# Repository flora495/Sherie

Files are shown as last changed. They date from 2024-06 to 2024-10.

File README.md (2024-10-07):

# Sherie
Sherieはオーソリニアな40％キーボードです。

## 組み立て方法
ほとんどの部品は実装済みです。
リセットスイッチとキーソケットだけはんだ付けしてください。
そのあと組み立ててください。

## ファームウェア書き込み
QMK toolboxを使って.hexファイルをキーボードに書き込んでください。QMK MSYSやpromicro web updaterでは書き込めない可能性があります。

## VIA/REMAP
viaのキーマップを書き込んだ上で
jsonファイルは以下を読み込ませることで、via/remapを使用することができます。
qmk_firmware\sherie\keymaps\via\sherie.json 

## コマンド
cd 
`cd /c/Users/F/qmk_firmware/keyboards/sherie`
コンパイル
`qmk compile -kb sherie -km default`
`qmk compile -kb sherie -km via`
フラッシュ(フラッシュはQMK toolboxを使うことを推奨します)
`qmk flash -kb sherie -km default`

## memo

USBとかの周りはGNDベタにしたほうがいいかも。
udb-sのPCBを参照。

## Ref
[1]https://note.com/copkbd/n/n587afde1812e

ATMEGA32U4直付の手順は以下を参照します。
[2]https://wiki.ai03.com/books/pcb-design/chapter/pcb-designer-guide

[3]https://taro-hayashi.github.io/LetsMakeaKeypadWithAtmega32u2/

typeC周りの回路
[4]https://github.com/Unified-Daughterboard/UDB-S

静電気対策（特に金属ケースの場合は参照）
[5]https://gist.github.com/s-show/286ffb1f5d9c886b514ff7a37e6d8d37

ベタGNDとか
[6]https://taro-hayashi.github.io/LetsMakeaKeypadWithAtmega32u2/

[7]https://qiita.com/Sugimoto_Yuuki/items/860ca6a57c2501f1cbab

[8]https://docs.qmk.fm/driver_installation_zadig

## バグ
QMK MSYSでflashできない場合
以下のようなエラーが出てflashに失敗する場合があります。

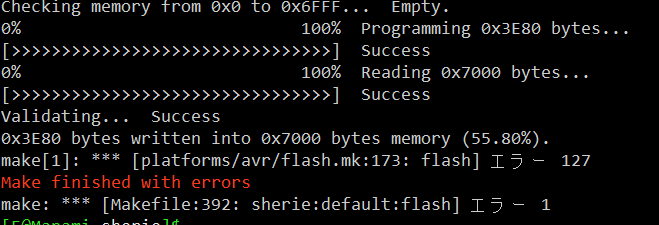
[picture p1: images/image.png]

<br>
これは実はエラーができても書き込み自体はできているっぽいです。
<br>
エラーなく書き込みたい場合は、QMK Toolboxを使って書き込みます。
<br>
エラーの原因はよくわからないが、おそらくポートのデバイスではなくてUSBデバイスとして認識しているのが原因。
<br>
おそらくですが、USBのドライバーが原因でした。[7]を参照し、ドライバーをWinUSBに書き換えます。こうするとQMK toolboxでエラーなしで読み込むことができるようになりました。
ただし、winUSBにするとQMK MSYSではflashできないぽいです。
ちなみにドライバーを変えるとシリアルポートで認識するようにもでるようにもできるっぽいです。
ただ、[8]によると、atmega32uの推奨driverはwinUSBなので、大人しく従う方がいいと思います。

## 改良点
1. 真ん中にネジ穴追加
1. スタビライザーのネジ穴のワッシャー分もボトムプレートの範囲を広げる
1. 電源のLEDが明るすぎる。暗くするのと、ジャンパでLEDを接続しないこともできるようにする
1. ブートローダー書き込みモードのときに光るLEDを追加する。
1. 1.5uのキーにもスタビライザーを追加？

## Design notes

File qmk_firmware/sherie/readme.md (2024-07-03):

# sherie

sherie

*A short description of the keyboard/project*

* Keyboard Maintainer: [F S](https://github.com/F S)
* Hardware Supported: *The PCBs, controllers supported*
* Hardware Availability: *Links to where you can find this hardware*

Make example for this keyboard (after setting up your build environment):

    make sherie:default

Flashing example for this keyboard:

    make sherie:default:flash

See the [build environment setup](https://docs.qmk.fm/#/getting_started_build_tools) and the [make instructions](https://docs.qmk.fm/#/getting_started_make_guide) for more information. Brand new to QMK? Start with our [Complete Newbs Guide](https://docs.qmk.fm/#/newbs).

## Bootloader

Enter the bootloader in 3 ways:

* **Bootmagic reset**: Hold down the key at (0,0) in the matrix (usually the top left key or Escape) and plug in the keyboard
* **Physical reset button**: Briefly press the button on the back of the PCB - some may have pads you must short instead
* **Keycode in layout**: Press the key mapped to `QK_BOOT` if it is available

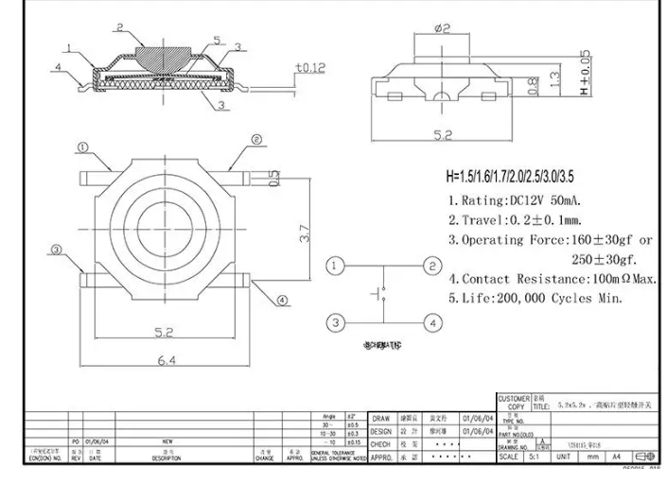
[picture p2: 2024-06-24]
Kicad/スクリーンショット 2024-06-19 001409.png

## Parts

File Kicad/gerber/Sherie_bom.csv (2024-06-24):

Reference | Value | Datasheet | Footprint | Qty | DNP
U2 | TPD4E05U06DQAR |  | acheron_Components:USON-10_2.5x1.0mm_P0.5mm | 1
C1 | 1uF | ~ | Capacitor_SMD:C_0805_2012Metric | 1
C2,C3,C4 | 0.1uF | ~ | Capacitor_SMD:C_0805_2012Metric | 3
C5 | 10uF | ~ | Capacitor_SMD:C_0805_2012Metric | 1
C6,C7 | 22pF | ~ | Capacitor_SMD:C_0805_2012Metric | 2
Y1 | 16MHz | ~ | Crystal:Crystal_SMD_3225-4Pin_3.2x2.5mm | 1
ESDD0 | ESD5Z5V0 | https://www.vishay.com/doc?85881 | Diode_SMD:D_SOD-523 | 1
F1 | SMD0805-050-16V | ~ | Fuse:Fuse_1206_3216Metric | 1
FB1 | GZ2012D601TF | ~ | Inductor_SMD:L_0805_2012Metric | 1
D1,D2,D3,D4,D5,D6,D7,D8,D9,D10,D11,D12,D13,D14,D15,D16,D17,D18,D19,D20,D21,D22,D23,D24,D25,D26,D27,D28,D29,D30,D31,D32,D33,D34,D35,D36,D37,D38,D39,D40,D41,D42,D43,D44,D45,D46,D47 | D | ~ | kbd_Parts:Diode_TH_SMD_without_holes | 47
LED1 | Green | ~ | my_footprints:LED0805-RD_GREEN | 1
U1 | ATmega32U4-A | http://ww1.microchip.com/downloads/en/DeviceDoc/Atmel-7766-8-bit-AVR-ATmega16U4-32U4_Datasheet.pdf | Package_QFP:TQFP-44_10x10mm_P0.8mm | 1
R1,R4 | 10k | ~ | Resistor_SMD:R_0805_2012Metric | 2
R2,R3 | 22 | ~ | Resistor_SMD:R_0805_2012Metric | 2
R5,R6 | 5.1k | ~ | Resistor_SMD:R_0805_2012Metric | 2
R7 | 1k | ~ | Resistor_SMD:R_0805_2012Metric | 1

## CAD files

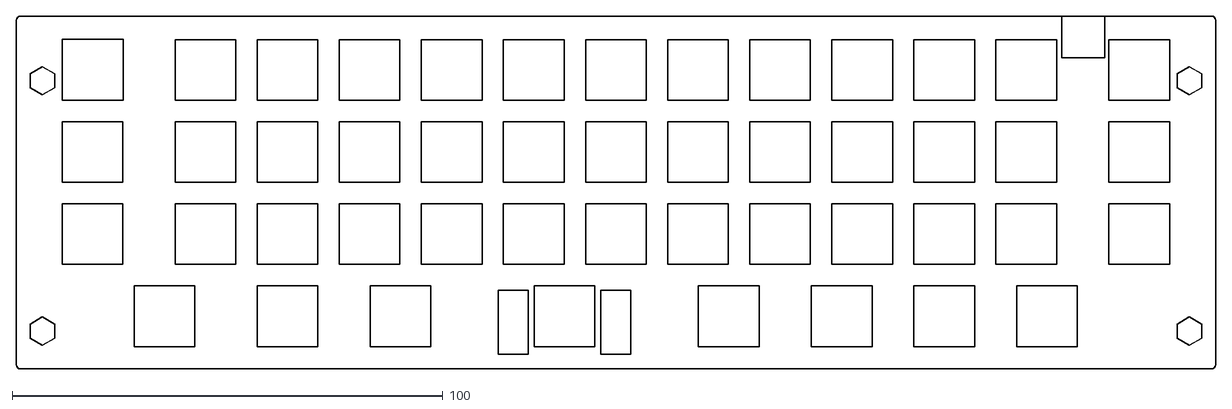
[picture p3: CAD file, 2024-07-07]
3dmodel/Sherie-top-acrylic-Edge_Cuts.dxf
278.3 x 81.9

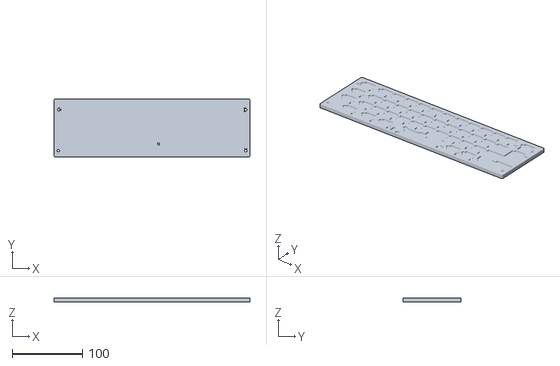
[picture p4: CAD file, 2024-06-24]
3dmodel/stl/Sherie-bottom v10.stl
278.3 x 81.9 x 5.00

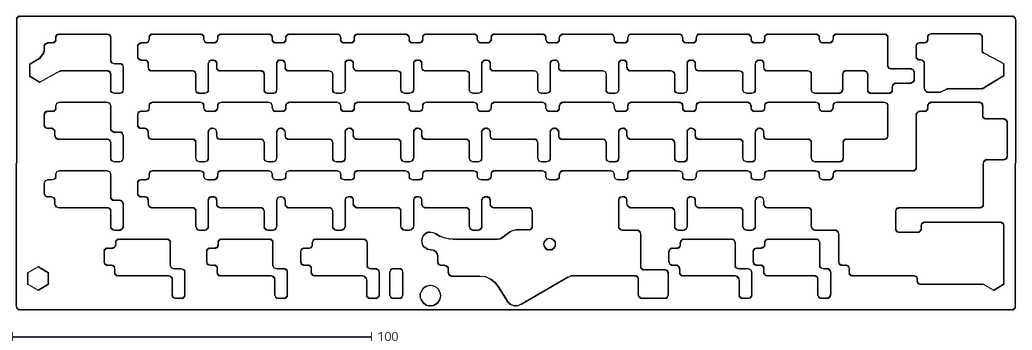
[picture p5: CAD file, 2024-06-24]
3dmodel/Sherie-User_4.dxf
278.3 x 81.9

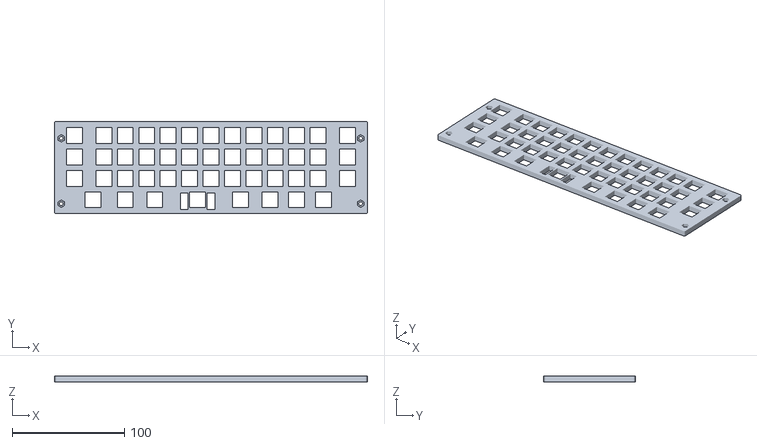
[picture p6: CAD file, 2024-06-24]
3dmodel/stl/Sherie-top v7.stl
278.3 x 81.9 x 5.00

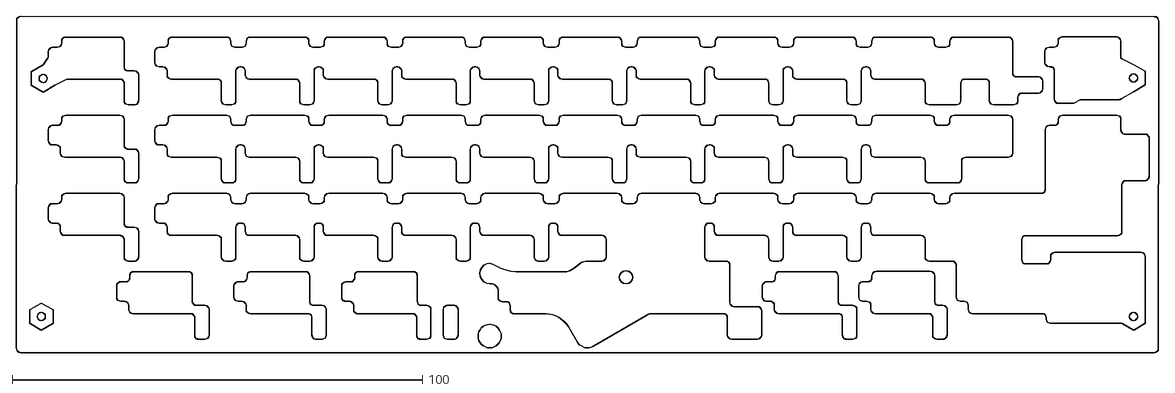
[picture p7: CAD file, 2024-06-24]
3dmodel/Sherie-bottom-Edge_Cuts.dxf
278.3 x 81.9

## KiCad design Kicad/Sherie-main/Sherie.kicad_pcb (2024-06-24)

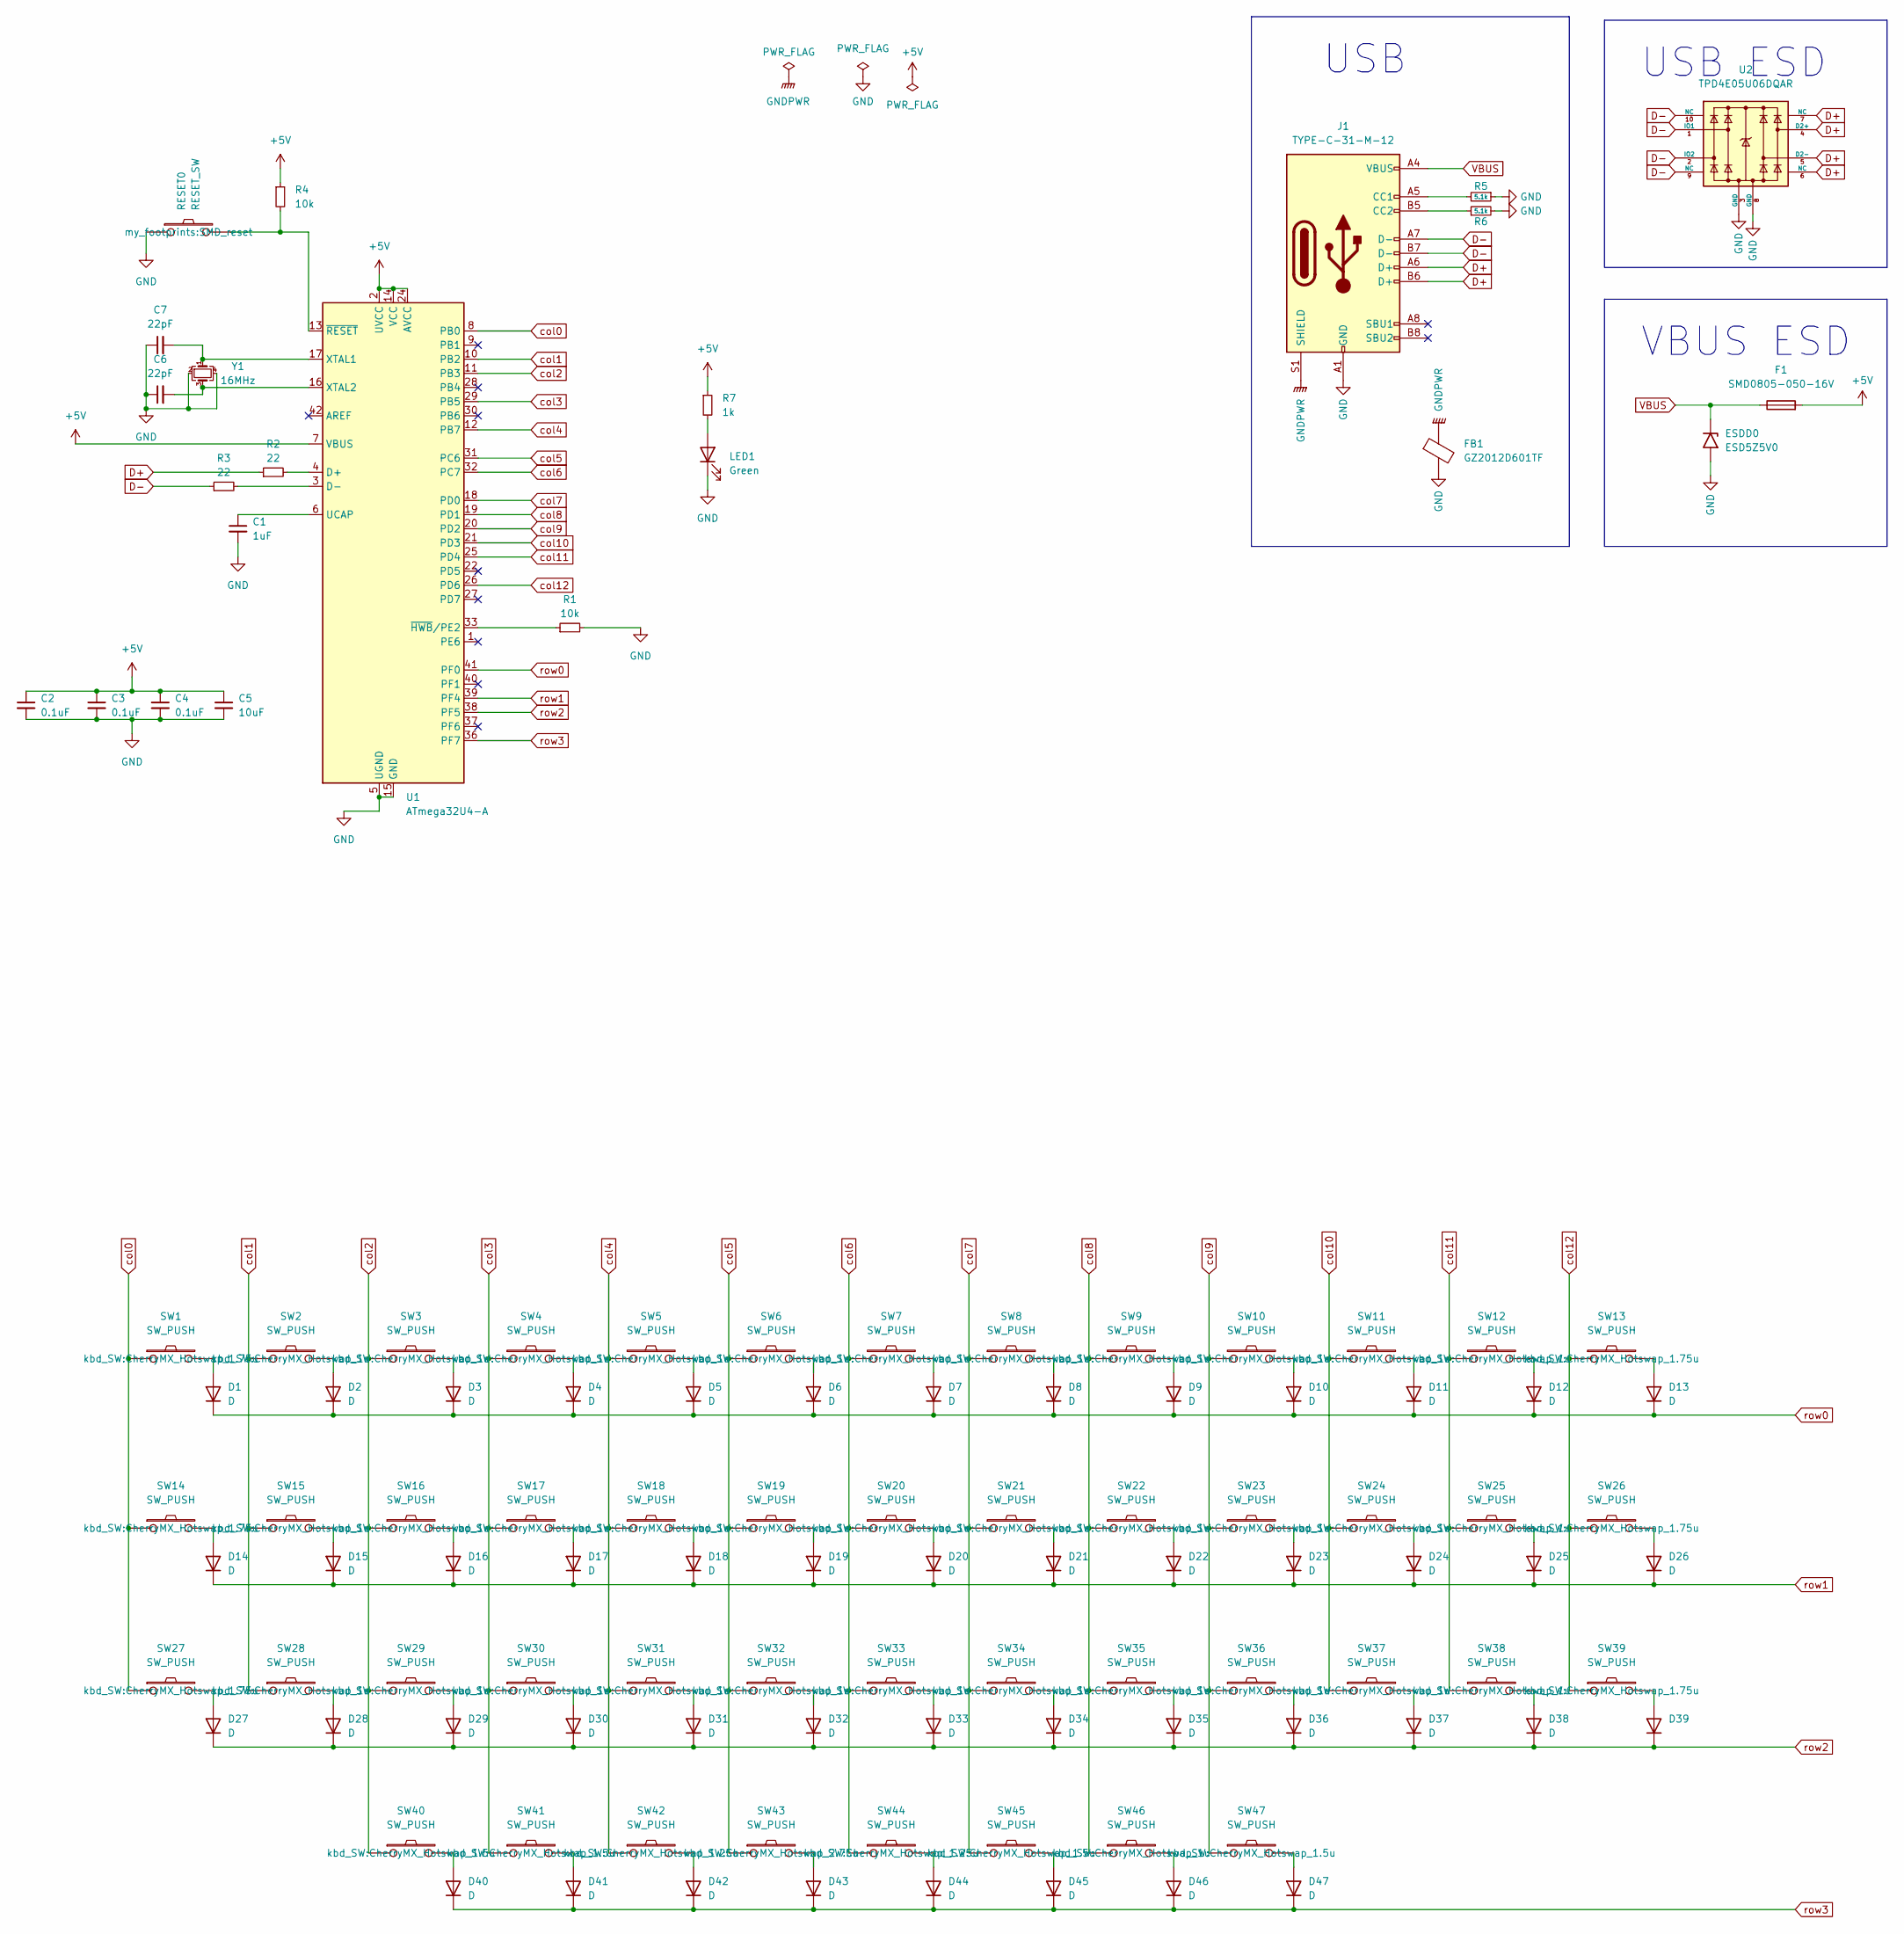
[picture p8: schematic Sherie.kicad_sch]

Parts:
C1: 1uF; C_0805_2012Metric
C2, C3, C4: 0.1uF; C_0805_2012Metric
C5: 10uF; C_0805_2012Metric
C6, C7: 22pF; C_0805_2012Metric
D1, D2, D3, D4, D5, D6, D7, D8, D9, D10, D11, D12, D13, D14, D15, D16, D17, D18, D19, D20, D21, D22, D23, D24, D25, D26, D27, D28, D29, D30, D31, D32, D33, D34, D35, D36, D37, D38, D39, D40, D41, D42, D43, D44, D45, D46, D47: D; Diode_TH_SMD_without_holes
ESDD0: ESD5Z5V0; D_SOD-523; Manufacturer Part Number ESD5Z5V0; LCSC Part Number C502546
F1: SMD0805-050-16V; Fuse_1206_3216Metric; Manufacturer Part Number SMD0805-050-16V; LCSC Part Number C2833485
FB1: GZ2012D601TF; L_0805_2012Metric; Manufacturer Part Number GZ2012D601TF; LCSC Part Number C1017
J1: TYPE-C-31-M-12; HRO-TYPE-C-31-M-12-Assembly; Manufacturer Part Number TYPE-C-31-M-12; LCSC Part Number C165948
LED1: Green; LED0805-RD_GREEN
R1, R4: 10k; R_0805_2012Metric
R2, R3: 22; R_0805_2012Metric
R5, R6: 5.1k; R_0805_2012Metric
R7: 1k; R_0805_2012Metric
RESET0: RESET_SW; SMD_reset
SW1, SW13, SW14, SW26, SW27, SW39: SW_PUSH; CherryMX_Hotswap_1.75u
SW2, SW3, SW4, SW5, SW6, SW7, SW8, SW9, SW10, SW11, SW12, SW15, SW16, SW17, SW18, SW19, SW20, SW21, SW22, SW23, SW24, SW25, SW28, SW29, SW30, SW31, SW32, SW33, SW34, SW35, SW36, SW37, SW38, SW46: SW_PUSH; CherryMX_Hotswap_1u
SW40, SW41, SW45, SW47: SW_PUSH; CherryMX_Hotswap_1.5u
SW42, SW44: SW_PUSH; CherryMX_Hotswap_1.25u
SW43: SW_PUSH; CherryMX_Hotswap_2.75u
U1: ATmega32U4-A; TQFP-44_10x10mm_P0.8mm
U2: TPD4E05U06DQAR; USON-10_2.5x1.0mm_P0.5mm; Manufacturer Part Number TPD4E05U06DQAR; LCSC Part Number C2836386
Y1: 16MHz; Crystal_SMD_3225-4Pin_3.2x2.5mm

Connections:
+5V: C2.1, C3.1, C4.1, C5.1, F1.2, R4.1, R7.1, U1.2 (UVCC), U1.7 (VBUS), U1.14 (VCC), U1.24 (AVCC), U1.34 (VCC), U1.44 (AVCC)
D+: J1.A6 (D+), J1.B6 (D+), R2.1, U2.4 (D2+), U2.5 (D2-), U2.6 (NC), U2.7 (NC)
D-: J1.A7 (D-), J1.B7 (D-), R3.1, U2.1 (IO1), U2.2 (IO2), U2.9 (NC), U2.10 (NC)
GND: C1.2, C2.2, C3.2, C4.2, C5.2, C6.1, C7.1, ESDD0.2 (A2), FB1.2, J1.A1 (GND), J1.A12 (GND), J1.B1 (GND), J1.B12 (GND), LED1.1 (K), R1.2, R5.1, R6.2, RESET0.1, U1.5 (UGND), U1.15 (GND), U1.23 (GND), U1.35 (GND), U1.43 (GND), U2.3 (GND), U2.8 (GND), Y1.2, Y1.4
GNDPWR: FB1.1, J1.S1 (SHIELD)
unnamed: D1.2 (A), SW1.2
unnamed: D2.2 (A), SW2.2
unnamed: D3.2 (A), SW3.2
unnamed: D4.2 (A), SW4.2
unnamed: D5.2 (A), SW5.2
unnamed: D6.2 (A), SW6.2
unnamed: D7.2 (A), SW7.2
unnamed: D8.2 (A), SW8.2
unnamed: D9.2 (A), SW9.2
unnamed: D10.2 (A), SW10.2
unnamed: D11.2 (A), SW11.2
unnamed: D12.2 (A), SW12.2
unnamed: D13.2 (A), SW13.2
unnamed: D14.2 (A), SW14.2
unnamed: D15.2 (A), SW15.2
unnamed: D16.2 (A), SW16.2
unnamed: D17.2 (A), SW17.2
unnamed: D18.2 (A), SW18.2
unnamed: D19.2 (A), SW19.2
unnamed: D20.2 (A), SW20.2
unnamed: D21.2 (A), SW21.2
unnamed: D22.2 (A), SW22.2
unnamed: D23.2 (A), SW23.2
unnamed: D24.2 (A), SW24.2
unnamed: D25.2 (A), SW25.2
unnamed: D26.2 (A), SW26.2
unnamed: D27.2 (A), SW27.2
unnamed: D28.2 (A), SW28.2
unnamed: D29.2 (A), SW29.2
unnamed: D30.2 (A), SW30.2
unnamed: D31.2 (A), SW31.2
unnamed: D32.2 (A), SW32.2
unnamed: D33.2 (A), SW33.2
unnamed: D34.2 (A), SW34.2
unnamed: D35.2 (A), SW35.2
unnamed: D36.2 (A), SW36.2
unnamed: D37.2 (A), SW37.2
unnamed: D38.2 (A), SW38.2
unnamed: D39.2 (A), SW39.2
unnamed: D40.2 (A), SW40.2
unnamed: D41.2 (A), SW41.2
unnamed: D42.2 (A), SW42.2
unnamed: D43.2 (A), SW43.2
unnamed: D44.2 (A), SW44.2
unnamed: D45.2 (A), SW45.2
unnamed: D46.2 (A), SW46.2
unnamed: D47.2 (A), SW47.2
unnamed: J1.A5 (CC1), R5.2
unnamed: J1.B5 (CC2), R6.1
unnamed: LED1.2 (A), R7.2
unnamed: R2.2, U1.4 (D+)
unnamed: R3.2, U1.3 (D-)
unnamed: C1.1, U1.6 (UCAP)
unnamed: C7.2, U1.17 (XTAL1), Y1.1
unnamed: C6.2, U1.16 (XTAL2), Y1.3
unnamed: R1.1, U1.33 (~HWB/PE2)
unnamed: R4.2, RESET0.2, U1.13 (~RESET)
VBUS: ESDD0.1 (A1), F1.1, J1.A4 (VBUS), J1.A9 (VBUS), J1.B4 (VBUS), J1.B9 (VBUS)
col0: SW1.1, SW14.1, SW27.1, U1.8 (PB0)
col1: SW2.1, SW15.1, SW28.1, U1.10 (PB2)
col2: SW3.1, SW16.1, SW29.1, SW40.1, U1.11 (PB3)
col3: SW4.1, SW17.1, SW30.1, SW41.1, U1.29 (PB5)
col4: SW5.1, SW18.1, SW31.1, SW42.1, U1.12 (PB7)
col5: SW6.1, SW19.1, SW32.1, SW43.1, U1.31 (PC6)
col6: SW7.1, SW20.1, SW33.1, SW44.1, U1.32 (PC7)
col7: SW8.1, SW21.1, SW34.1, SW45.1, U1.18 (PD0)
col8: SW9.1, SW22.1, SW35.1, SW46.1, U1.19 (PD1)
col9: SW10.1, SW23.1, SW36.1, SW47.1, U1.20 (PD2)
col10: SW11.1, SW24.1, SW37.1, U1.21 (PD3)
col11: SW12.1, SW25.1, SW38.1, U1.25 (PD4)
col12: SW13.1, SW26.1, SW39.1, U1.26 (PD6)
row0: D1.1 (K), D2.1 (K), D3.1 (K), D4.1 (K), D5.1 (K), D6.1 (K), D7.1 (K), D8.1 (K), D9.1 (K), D10.1 (K), D11.1 (K), D12.1 (K), D13.1 (K), U1.41 (PF0)
row1: D14.1 (K), D15.1 (K), D16.1 (K), D17.1 (K), D18.1 (K), D19.1 (K), D20.1 (K), D21.1 (K), D22.1 (K), D23.1 (K), D24.1 (K), D25.1 (K), D26.1 (K), U1.39 (PF4)
row2: D27.1 (K), D28.1 (K), D29.1 (K), D30.1 (K), D31.1 (K), D32.1 (K), D33.1 (K), D34.1 (K), D35.1 (K), D36.1 (K), D37.1 (K), D38.1 (K), D39.1 (K), U1.38 (PF5)
row3: D40.1 (K), D41.1 (K), D42.1 (K), D43.1 (K), D44.1 (K), D45.1 (K), D46.1 (K), D47.1 (K), U1.36 (PF7)

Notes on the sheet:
USB
USB ESD
VBUS ESD

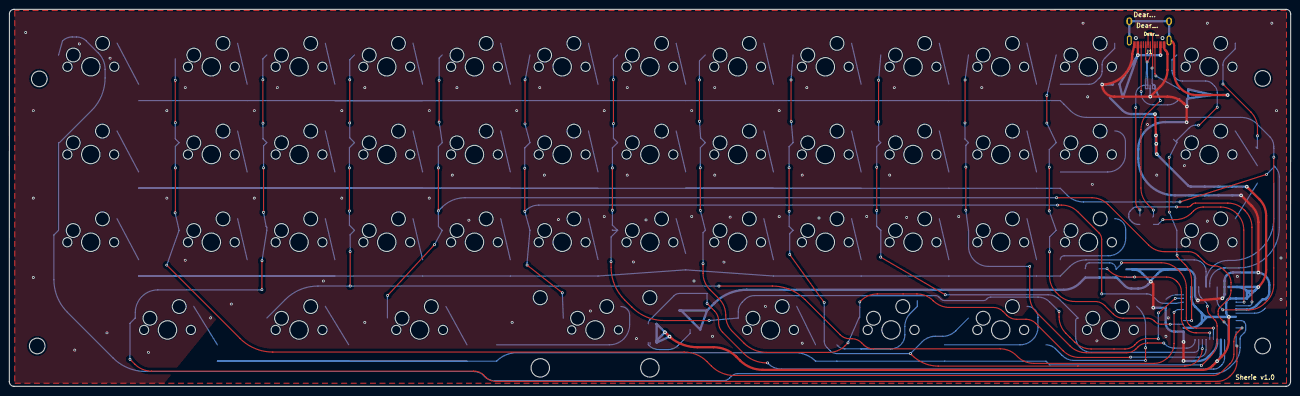
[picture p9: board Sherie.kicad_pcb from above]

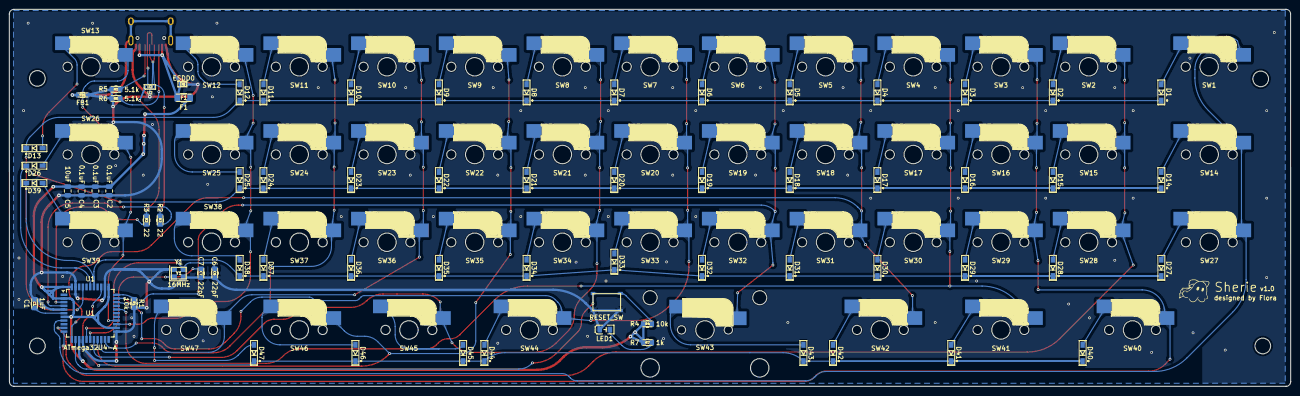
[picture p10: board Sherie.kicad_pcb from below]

Board: 2 copper layers, 278.3 x 81.9 mm, 117 parts (22 on the bottom side), 80 nets.

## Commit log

2024-06-24 v1.0完成
    [Sherie-B_Cu.gbr, Sherie-B_Mask.gbr, Sherie-B_Silkscreen.gbr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]
2024-07-03 色々コミット
2024-07-03 readmeを追記
2024-07-07 reamp対応など
    [Sherie-top-acrylic-Edge_Cuts.dxf, Sherie-top-acrylic.kicad_pcb, Sherie-top-acrylic.kicad_sch]
2024-07-07 README.mdを更新
